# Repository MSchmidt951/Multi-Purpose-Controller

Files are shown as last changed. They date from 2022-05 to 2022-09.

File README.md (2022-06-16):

# Multi Purpose Controller

This is a wireless controller that can be used with multiple devices and projects.  
It uses an ATmega644 to control the circuit and an nRF24LO1 for communication.  
More information on [my portfolio](https://mschmidt951.github.io/portfolio/projects/controller.html)

## Features

Controller inputs
- 6 general purpose buttons
- 2 general purpose switches
- 2 joysticks (with built in buttons)
- 2 trigger buttons
- A potentiometer
- An abort/shutdown button
- Standby mode switch
- A light button and switch

UART connector for addons

An RGB LED (PL9823) giving the status of the controller

## Usage

1. Turn the power switch on and wait for the orange light
2. Turn on the device that is being used
3. When the light turns green press some buttons!

LED colour | Meaning
---------- | ------------------------
Red        | Initialising or aborted
Orange     | Waiting for other device
Blue       | Standby mode
Green      | Sending data

## Installation and Setup

### Making the controller

Solder the circuit according to the circuit diagram
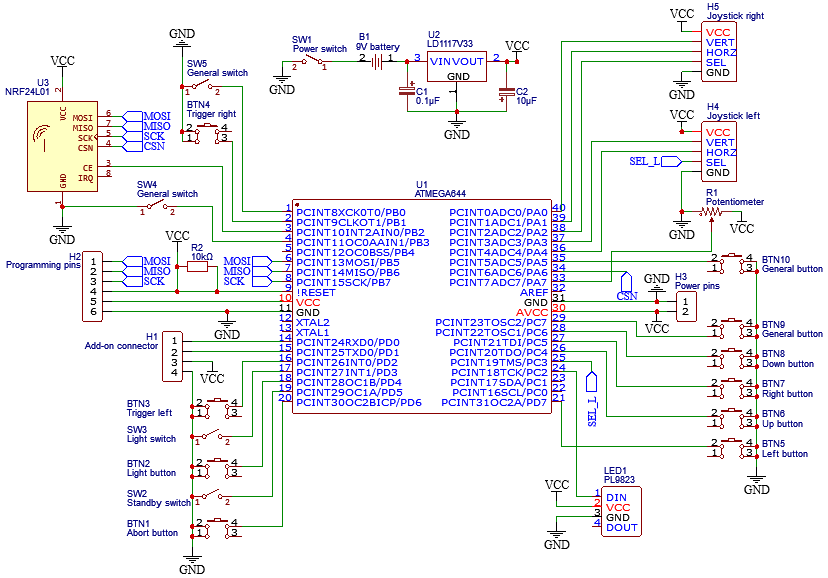
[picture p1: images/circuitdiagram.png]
Circuit Diagram


An example of a completed circuit (missing triggers) that is compatible with the prints  
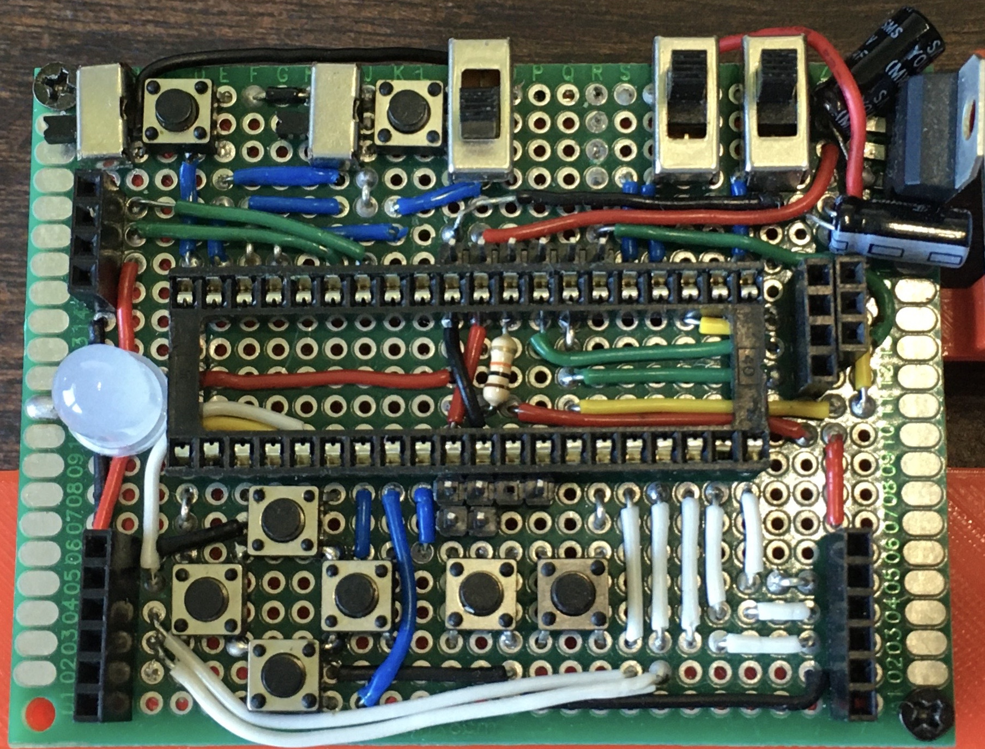
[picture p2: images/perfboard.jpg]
Soldered Circuit


3D print the base of the controller

Attach the electronics to the print with screws

### Uploading the code

Install the [RF24](https://github.com/nRF24/RF24) and [FastLED](https://github.com/FastLED/FastLED) libraries and [MightyCore](https://github.com/MCUdude/MightyCore) on the arduino IDE

Load the [code](https://github.com/MSchmidt951/Multi-Purpose-Controller/blob/main/controller/controller.ino) into the arduino IDE then under Tools > Board > MightyCore select ATmega644

Make sure the standard pinout and internal clock is selected in the settings then upload the code to the ATmega644

## Example Receiver

[receiverExample.ino](https://github.com/MSchmidt951/Multi-Purpose-Controller/blob/main/receiverExample/receiverExample.ino) shows an example of each of the inputs of the controller being used to control another microcontroller using radio

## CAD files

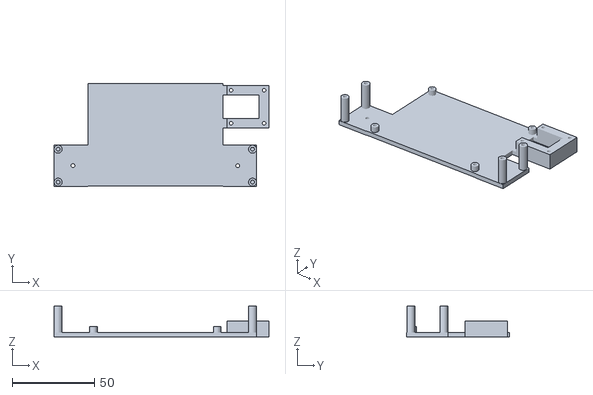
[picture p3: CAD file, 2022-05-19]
3D files/Controller.stl
130.5 x 62.3 x 18.8

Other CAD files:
3D files/Controller.blend

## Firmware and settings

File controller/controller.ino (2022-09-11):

#include <RF24.h>
#include <FastLED.h>

RF24 radio(2, 30);
byte addresses[][6] = {"C","D"};

CRGB led[1];
const int LEDbrightness = 45;
bool aborted = false;

//Input pins
const int ABORT = 14;
const int Standby = 13;
const int lightBtn = 12;
const int lightSwitch = 11;
const int switches[3] = {4, 3, 0}; //L, M, R
const int triggers[2] = {10, 1}; //L, R

const int dirBtns[4] = {15, 21, 20, 22}; //L, R, U, D
const int btns[2] = {23, 29}; //L, R
const int pot = 31;

const int StickL[3] = {27, 28, 19}; //x, y, JstickBtnL
const int StickR[3] = {25, 24, 26}; //r, z, JstickBtnR

//Data bytes
byte btnByte; //0-3:directional buttons, 4-5:misc buttons, 6-7:triggers
byte miscByte; //0:abort, 1:standby, 2:light, 3-5:switches, 6-7:JstickBtns
char sendData[7]; //[x, y, r, z, pot, btnByte, miscByte]

//Functions

void setLED(int r, int g, int b){
  fill_solid(led, 1, CRGB(r, g, b));
  FastLED.show();
}

int toInt(float f){
  return int(f + 0.5);
}


void setup(){
  //Set up controls
  pinMode(ABORT, INPUT_PULLUP);
  pinMode(Standby, INPUT_PULLUP);
  pinMode(lightBtn, INPUT_PULLUP);
  pinMode(lightSwitch, INPUT_PULLUP);
  for (int i=1; i<3; i++){
    pinMode(switches[i], INPUT_PULLUP);
  }
  for (int i=0; i<2; i++){
    pinMode(triggers[i], INPUT_PULLUP);
  }
  
  for (int i=0; i<4; i++){
    pinMode(dirBtns[i], INPUT_PULLUP);
  }
  for (int i=0; i<4; i++){
    pinMode(btns[i], INPUT_PULLUP);
  }
  pinMode(pot, INPUT_PULLUP);
  
  for (int i=0; i<2; i++){
    pinMode(StickL[i], INPUT);
    pinMode(StickR[i], INPUT);
  }
  pinMode(StickL[2], INPUT_PULLUP);
  pinMode(StickR[2], INPUT_PULLUP);

  //Set up LED
  delay(2000);
  FastLED.addLeds<WS2812, 18>(led, 1);
  
  //Set up communication
  setLED(150, 0, 0);
  delay(1000);
  radio.begin();
  radio.setRadiation(RF24_PA_MAX, RF24_2MBPS);
  radio.setChannel(124);
  radio.setPayloadSize(7);

  //Open pipe
  radio.openWritingPipe(addresses[0]);
  radio.openReadingPipe(1, addresses[1]);
  radio.startListening();

  //Waits until device is on
  setLED(80, 18, 2);
  bool Ready = false;
  while (!Ready){
    //Check radio for other device
    if (radio.available()) {
      while (radio.available()) {
        radio.read(&miscByte, sizeof(byte));
      }
      Ready = miscByte > 0;
    }

    //If both the left and right joysticks are pressed continue with main loop
    if (!digitalRead(StickL[2]) and !digitalRead(StickR[2])) {
      Ready = true;
    }

    delay(2);
  }
  radio.stopListening();
  setLED(0, LEDbrightness, 0);
}

void loop(){
  //Set the LED colours
  if (!digitalRead(Standby)){
    setLED(0, 0, LEDbrightness);
    aborted = false;
  } else if (!digitalRead(ABORT) or aborted) {
    setLED(LEDbrightness, 0, 0);
    aborted = true;
  } else {
    setLED(0, LEDbrightness, 0);
  }
  
  /* Get input */
  //Get joystick input, it is put between 0-254
  sendData[0] = toInt(analogRead(StickL[0])/4.03); //x
  sendData[1] = toInt(analogRead(StickL[1])/4.03); //y
  sendData[2] = toInt(analogRead(StickR[0])/4.03); //r
  sendData[3] = toInt(analogRead(StickR[1])/4.03); //z
  //Get potentiometer input, it is put between 0-255
  sendData[4] = toInt(analogRead(pot)/4.01);
  
  //Get button inputs
  for (int i=0; i<4; i++){
    bitWrite(btnByte, i, !digitalRead(dirBtns[i]));
  }
  bitWrite(btnByte, 4, !digitalRead(btns[0]));
  bitWrite(btnByte, 5, !digitalRead(btns[1]));
  bitWrite(btnByte, 6, !digitalRead(triggers[0]));
  bitWrite(btnByte, 7, !digitalRead(triggers[1]));
  sendData[5] = btnByte;
  
  //Get inputs for miscByte
  bitWrite(miscByte, 0, !digitalRead(ABORT));
  bitWrite(miscByte, 1, !digitalRead(Standby));
  if (!digitalRead(lightSwitch)) {
    bitWrite(miscByte, 2, digitalRead(lightBtn));
  } else {
    bitWrite(miscByte, 2, !digitalRead(lightBtn));
  }
  for (int i=1; i<3; i++){
    bitWrite(miscByte, i+3, !digitalRead(switches[i]));
  }
  bitWrite(miscByte, 6, !digitalRead(StickL[2]));
  bitWrite(miscByte, 7, !digitalRead(StickR[2]));
  sendData[6] = miscByte;

  /* Send data */
  radio.write(&sendData, sizeof(char[7]));
}

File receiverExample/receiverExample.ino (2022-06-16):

#include <RF24.h>

//Program settings
const int showBinary = false;
const int showAnalogue = false;
const int showDigital = true;

//Radio vars
RF24 radio(6, 7); //Sets CE and CSN pins of the radio, can be set to any pin
byte addresses[][6] = {"C", "D"};
char rawData[7]; //Raw input data from radio
byte Data[7]; //Usable input data from radio

void checkData(int byteIndex, int index, String inputName) {
  if (bitRead(Data[byteIndex], index)) {
    Serial.print(inputName + ", ");
  }
}

void setup(){
  pinMode(10,OUTPUT);
  digitalWrite(10,HIGH);
  
  //Start the serial communication
  Serial.begin(57600);
  while (!Serial);
  
  //Set up communication
  Serial.print("\n\nSetting up radio ... ");
  radio.begin();
  radio.setPALevel(RF24_PA_MAX);
  radio.setDataRate(RF24_1MBPS);
  radio.setChannel(124);
  
  //Open pipe
  radio.openWritingPipe(addresses[1]);
  radio.openReadingPipe(1, addresses[0]);
  
  //Ready device
  for (int i=0; i<10; i++){
    radio.write(0b01010101, 1);
    delay(20);
  }
  radio.startListening();

  Serial.println("done!");
}

void loop(){
  if (radio.available()) {
    //Get data from controller
    while (radio.available()) {
      radio.read(&rawData, sizeof(char[7]));
    }
    for (int i=0; i<7; i++) {
      Data[i] = byte(rawData[i]);
    }

    //Print the data in binary
    if (showBinary) {
      Serial.print("Raw binary data: ");
      for (int i=0; i<7; i++) {
        Serial.print(byte(Data[i]), BIN);
        Serial.print(" ");
      }
      Serial.println();
    }

    /* Process the data */

    if (showAnalogue){
      Serial.print("Joysticks: ");
  
      //Read the horizontal axis of the left joystick
      Serial.print((Data[0] - 127)/1.27); //Range of -100 to 100
      Serial.print(" ");
  
      //Read the vertical axis of the left joystick
      Serial.print((Data[1] - 127)/1.27);
      Serial.print("  ");
  
      //Read the horizontal axis of the right joystick
      Serial.print((Data[2] - 127)/1.27);
      Serial.print(" ");
  
      //Read the vertical axis of the right joystick
      Serial.print((Data[3] - 127)/1.27);
      Serial.print("   ");
  
      //Read the potentiometer
      Serial.print("Potentiometer: ");
      Serial.println((Data[4]-3)/2.52); //Range of 0 to 100
    }

    //Read the byte containing most of the buttons and the misc data
    if (showDigital) {
      Serial.print("Controls pressed: ");
      checkData(5, 0, "left");
      checkData(5, 1, "right");
      checkData(5, 2, "up");
      checkData(5, 3, "down");
      checkData(5, 4, "general left");
      checkData(5, 5, "general right");
      checkData(5, 6, "left trigger");
      checkData(5, 7, "right trigger");
      
      checkData(6, 0, "abort");
      checkData(6, 1, "standby");
      checkData(6, 2, "light");
      checkData(6, 4, "left switch");
      checkData(6, 5, "right switch");
      checkData(6, 6, "left joystick button");
      checkData(6, 7, "right joystick button");
      
      Serial.println();
    }
  }

  delay(10);
}

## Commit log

2022-05-19 Inital commit
    [Controller.blend, Controller.stl]
2022-05-29 Fixed sending same signal for all switches
    [controller.ino]
2022-06-16 Fixed switches on receiver
    [receiverExample.ino]
2022-06-16 Changed abort lighting
    The LED now resets the abort colour when the standby switch is true
    [controller.ino]
2022-06-16 Controller now can be readied manually
    The controller can be readied (continue to main loop) when pressing both joystick buttons down
